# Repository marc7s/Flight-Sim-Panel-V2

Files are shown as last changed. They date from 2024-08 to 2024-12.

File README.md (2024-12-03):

# Flight Sim Panel V2
A rework of the [Flight Sim Panel V2](https://forums.flightsimulator.com/t/3d-printed-flight-simulator-panel-v2/219057) by [Aaron Cobb](https://www.cobbinnovation.com/).

I have modified some of the 3D models, and refactored the code. Here's what the finished product looks like.

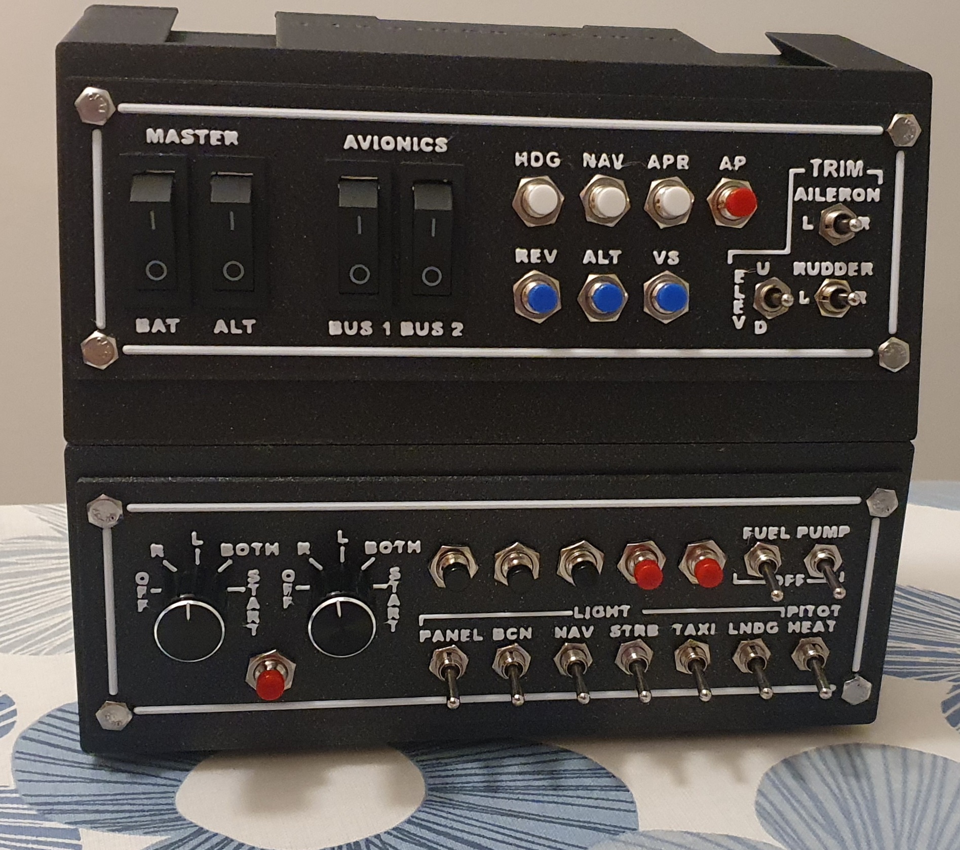
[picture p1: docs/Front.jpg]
Front


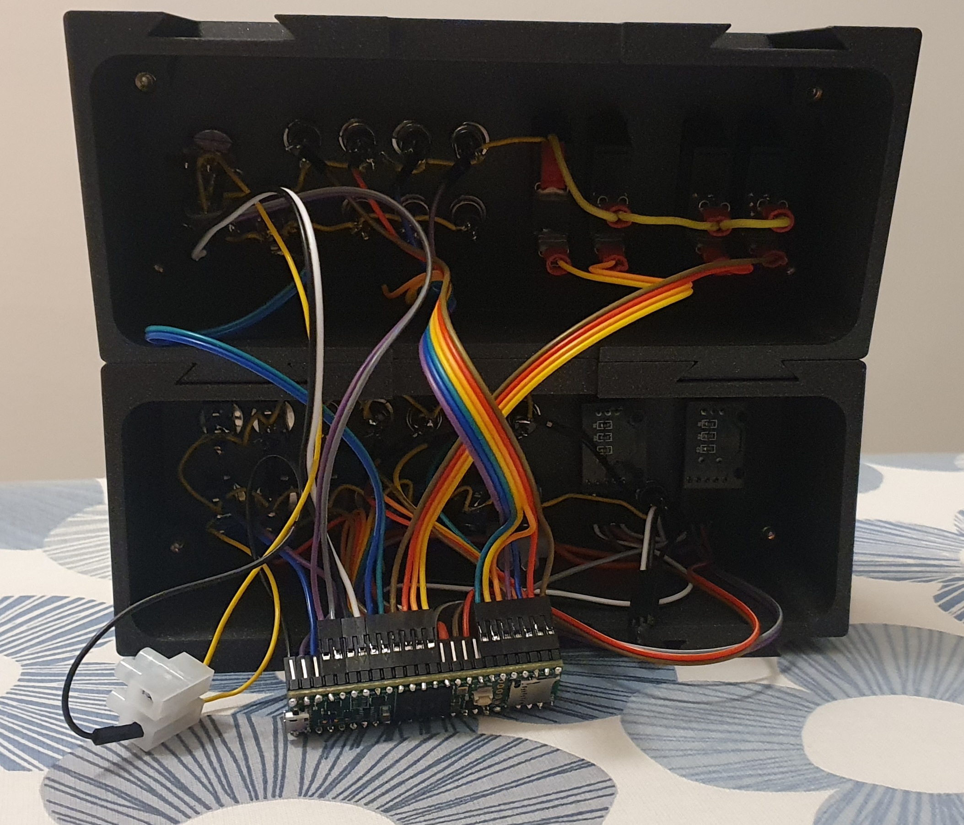
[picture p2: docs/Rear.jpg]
Rear


# Source code refactor
The main point of the refactor was to make it easier to have different pin layouts than the original, to make it more flexible. Note however, that this is of course at your own risk. It is up to you to make sure you do not reuse pins, or cause short-circuits or in any way harm the equipment.

The configuration has been migrated to variables, where the pin numbers and joystick bindings are set in a single place. To change the pin layout, or the joystick mapping for that matter, you therefore only need to change the code in a single place.

# 3D models
I only provide the 3D models that I have modified. There are a lot more available from Aaron Cobb in the previously linked forum post. I have recreated two enclosures to fit threaded inserts for mounting the panels. For each enclosure, you will need a panel. These are found among those 3D models by Aaron Cobb. The exception is the `PNL-MSTR-Auto-Trim` which I have recreated since the button holes were the incorrect size (3,05mm radius instead of 3,5mm like the rest). This version has the correct size button holes, so the buttons fit without having to drill them. This project as seen in the images was created with two stacked enclosures (0deg bottom, 15deg top) with the `PNL-MSTR-Auto-Trim` top panel and `PNL-Mags-Lights-Fuel-Xtra` bottom panel in mind. However, you are free to create any setup you want, although you might need to modify the code and/or 3D models in that case.

The modular enclosures have been modified to fit threaded inserts, to avoid any damage to the plastic parts caused by screwing directly into the printed part. Each enclosure uses 4 threaded inserts. I used the [M4x8,1 threaded inserts from CNCKitchen](https://cnckitchen.store/products/gewindeeinsatz-threaded-insert-m4-standard-50-stk-pcs). The hole for the insert is 5,6mm in diameter, in line with the specifications for that specific threaded insert, should you find other alternatives that work with the same hole diameter.

I have provided Autodesk Fusion 360 project files for all models I have created so you can easily modify them to your need, under the terms of the license. I also recreated the blank panel, should you want to more easily create your own panels in Fusion 360 without having to work with the blank STL file.

# Thoughts and recommendations
After building this project, I have a few recommendations to make. Firstly, by far the most tedious and delicate part was soldering wires to the components and the Teensy. The margins are pretty small, and making sure all solder points give good connections without any accidental solder bridges, in combination with the cable strain causing solders to break made it an annoying process. Especially since the components are not made for direct wire soldering, and all look different. At that point, I decided to switch strategy and bought a kit for JST and Dupont connectors, which I had considered from the start but decided to try soldering first. JST connectors are superior, but unfortunately my XH-xA connectors had protrusions on the sides, meaning I could not put multiple connectors next to each other. Therefore, I opted for the Dupont connectors which are completely flush. Crimping the connectors was a bit tedious, but the connections were much easier to handle and more reliable, and allowed me to group them logically with regards to the components. If I would do this again, I would definately use Dupont connectors from the start, and also put in the extra time to crimp connectors for the component side as well, although the components do have different connector types which is rather annoying.

Also, I definately recommend printing the panels with a different color for the text, as it was hard to read on the single filament panels I printed in the beginning. In the end, I printed new multi material panels and transferred all components to them. I do not have multiple extruders, or a multi material unit for my printer, but printing multi material manually is easy with just a single filament change as in this case. I have provided the GCode for my Prusa MK4 for multi material (black and white Prusament PLA) with a single extruder, that prints the two mentioned panels with a manual filament change for the text. Should you have a different printer, filaments, or a multi material unit, you can as mentioned get the panels from Aaron Cobb and slice them yourself. This is a picture of the provided panels in single extruder multi material mode:

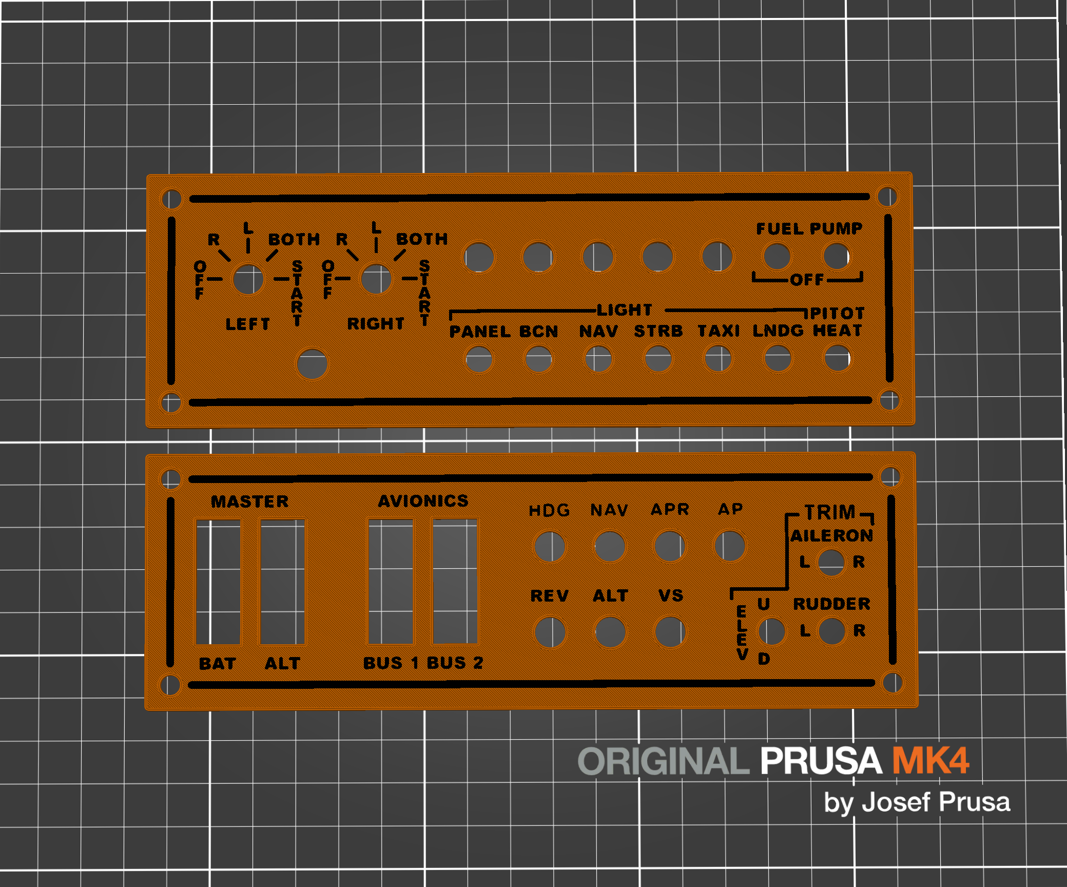
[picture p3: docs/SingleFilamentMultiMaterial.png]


Finally, I would use longer wires as short wires cause more strain and limit the positioning of the Teensy. I used longer wires for the top panel, but the shorter wires for the bottom panel were slightly too short meaning the Teensy was pretty difficult to position well. I designed a holder for the Teensy, but as it is already rather cramped inside the enclosures, and my wires were too short, I did not include it here or implement it in the design.

# Component list

Aaron Cobb also provided a component list in the linked forum post, however I am based in Europe and could therefore not find exactly the same components. Should you also face the same issue, I have also included the mounting hole sizes so you can find alternatives.

## Teensy microcontroller

* 1x [Teensy 4.1](https://www.amazon.se/dp/B08CXTSJV6)
* 2x [Male Pin Header](https://www.amazon.se/dp/B07DBY753C), more than 2 included in this kit

## Panel mounting to enclosure

Note that this is optional, but recommended. Alternatively you could use screws directly into the plastic, but this will of course damage the plastic and may cause them to come loose if you reuse the screw holes multiple times (for example when removing and putting the panel back on). Therefore, using threaded inserts is my recommendation which also provide better rigidity in the mounting.

* 4x per enclosure (8 total for this configuration) [5,6mm diameter M4 threaded inserts](https://cnckitchen.store/products/gewindeeinsatz-threaded-insert-m4-standard-50-stk-pcs)
* 4x per enclosure (8 total for this configuration) M4 machine screws

## MSTR Auto Trim panel

* 4x [Rocker Switches](https://www.amazon.se/dp/B00WJLF8OQ), mount hole size 10,2 x 29mm
* 7x [Momentary Push Buttons](https://www.amazon.se/dp/B07XRKN3F3), mount hole diameter 7mm
* 3x [Momentary Mini Toggle Switches](https://www.amazon.se/dp/B01M0LXR0L), mount hole diameter 6mm

## Mags Lights Fuel Xtra panel

* 2x [KY-040 Rotary Encoders](https://www.amazon.se/dp/B0D12N311C), mount hole size 7mm
* 6x [Momentary Push Buttons](https://www.amazon.se/dp/B07XRKN3F3), mount hole diameter 7mm
* 9x [Mini Toggle Switches](https://www.amazon.se/dp/B0B56S4F1X), mount hole diameter 6mm

# License
This work is shared under the same license as the original work, CC BY-NC-SA 4.0, in line with the license terms.

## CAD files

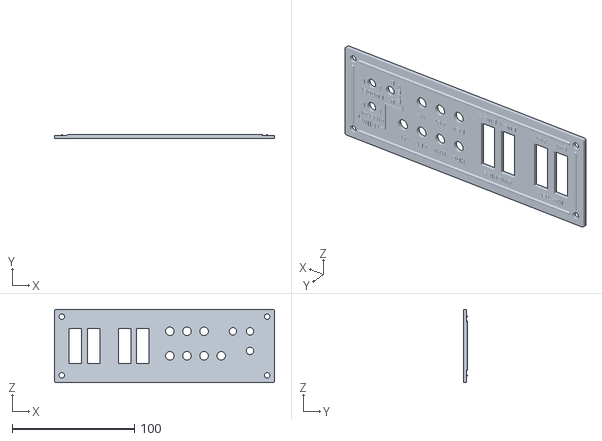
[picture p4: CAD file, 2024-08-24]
3D models/PNL-MSTR-Auto-Trim.stl
180.0 x 3.00 x 60.0

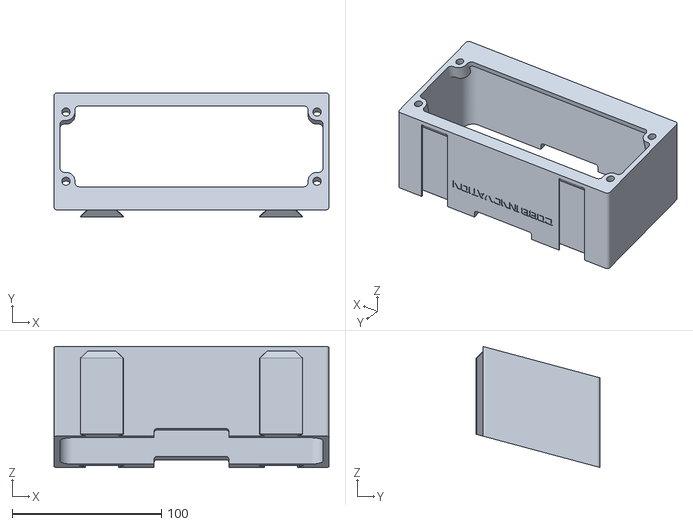
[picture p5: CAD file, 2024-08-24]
3D models/FP_ModularEnclosure_15-deg.stl
184.0 x 83.1 x 81.0

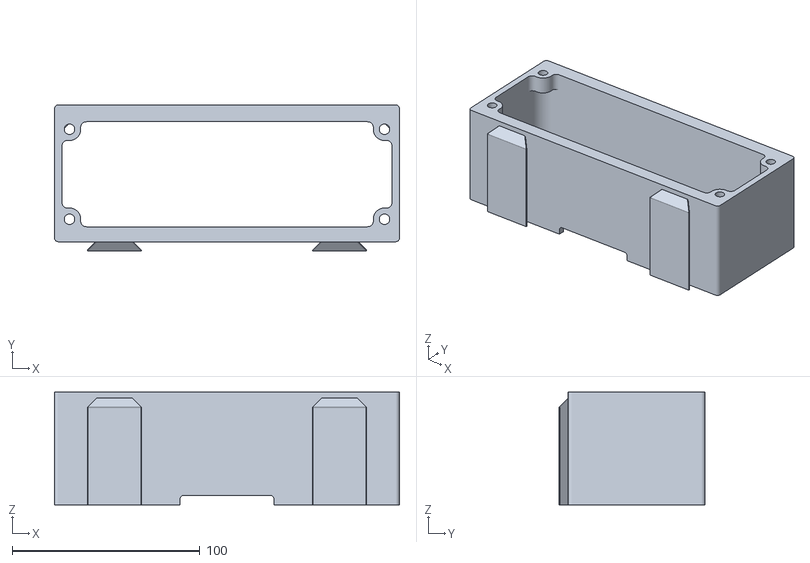
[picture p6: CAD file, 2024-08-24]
3D models/FP_ModularEnclosure_0-deg.stl
184.0 x 78.0 x 60.0

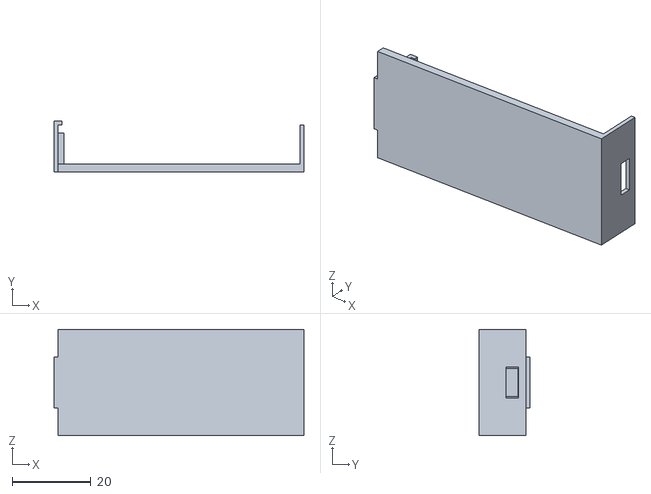
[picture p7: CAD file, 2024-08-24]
3D models/Teensy 4.1 Mount.stl
63.5 x 13.0 x 27.0

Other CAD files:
3D models/Flight Panel Blank.f3d
3D models/Modular Enclosure 0 deg.f3d
3D models/PNL-MSTR-Auto-Trim.f3d
3D models/Teensy 4.1 Mount.f3d

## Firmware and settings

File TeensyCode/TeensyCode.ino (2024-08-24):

/*
   Flight Sim Panel V2
   Created by Aaron Cobb, Refactored by Marcus Schagerberg
   https://www.cobbinnovation.com
   Board Used:		Teensy 4.1
   USB Type:		Flight Sim Controls + Joystick
   Upper Panel: PNL-MSTR-Auto-Trim
   Lower Panel: PNL-Mags-Lights-Fuel-Xtra


Following are the mapping between the components and the bindings, where you configurate the pin (on the Teensy board) and the joystick button/hat (that will be emulated by the Teensy)

***UPPER PANEL***		*Wired to right side of board, when looking at the side with the USB and SD card slot*
Rocker Switches
	Battery			      Rocker_Binding_Battery
	Alternator	      Rocker_Binding_Alternator
	Bus 1			        Rocker_Binding_Bus1
	Bus 2			        Rocker_Binding_Bus2
Momentary Buttons Group #1
	HDG				        Button_Binding_HDG
	NAV				        Button_Binding_NAV
	APR				        Button_Binding_APR
	AP				        Button_Binding_AP
	REV				        Button_Binding_REV
	ALT				        Button_Binding_ALT
	VS				        Button_Binding_VS
Trim Momentary Toggles
	Aileron Left	    Trim_Binding_AileronLeft
	Aileron Right	    Trim_Binding_AileronRight
	Rudder Left		    Trim_Binding_RudderLeft
	Rudder Right	    Trim_Binding_RudderRight
	Elevator Up		    Trim_Binding_ElevatorUp
	Elevator Down	    Trim_Binding_ElevatorDown
***LOWER PANEL***		*Wired to left side of board, when looking at the side with the USB and SD card slot*
Toggle Switches
  Fuel Pump Left	  Toggle_Binding_FuelPumpLeft
	Fuel Pump Right	  Toggle_Binding_FuelPumpRight
	Pitot Heat		    Toggle_Binding_PitotHeat
	LNDG			        Toggle_Binding_LNDG
	TAXI			        Toggle_Binding_TAXI
	STRB			        Toggle_Binding_STRB
	NAV				        Toggle_Binding_NAV
	BCN				        Toggle_Binding_BCN
	Panel			        Toggle_Binding_Panel
Momentary Buttons Group #2 *From left to right, starting with the button between the rotary encoders*
	BetweenRotaries	  Button_Binding_BetweenRotaries
	Unlabeled 1		    Button_Binding_Unlabeled1
	Unlabeled 2		    Button_Binding_Unlabeled2
	Unlabeled 3		    Button_Binding_Unlabeled3
	Unlabeled 4		    Button_Binding_Unlabeled4
	Unlabeled 5		    Button_Binding_Unlabeled5
Rotary Encoders *Note that they are run in low performance polling mode without interrupts* Also note that you need to wire them to ground and Vcc as well, and that CLK is CW and DT is CCW
  KnobLeft CCW	    Knob_Binding_LeftCCW
	KnobLeft CW		    Knob_Binding_LeftCW
	KnobLeft Click	  Knob_Binding_LeftClick
	KnobRight CCW	    Knob_Binding_RightCCW
	KnobRight CW	    Knob_Binding_RightCW
	KnobRight Click	  Knob_Binding_RightClick
*/
#include <Bounce.h>
struct ButtonBinding {
  int Pin;
  int JoystickButton;
  Bounce* Button = nullptr;
};

struct HatBinding {
  int Pin;
  int JoystickHat;
  Bounce* Button = nullptr;
};

// ***** Pin bindings *****
// Each binding has a pin number and a joystick button/hat. Configure them here below
// The bindings also contain a pointer to the joystick emulation, which is set up later
// Most also define an array of the bindings, so that they can be iterated later. Leave these arrays unless you add or remove bindings
// ***UPPER PANEL***
// Rocker Switches
ButtonBinding Rocker_Binding_Battery =          { 17, 1 };
ButtonBinding Rocker_Binding_Alternator =       { 16, 2 };
ButtonBinding Rocker_Binding_Bus1 =             { 15, 3 };
ButtonBinding Rocker_Binding_Bus2 =             { 14, 4 };
ButtonBinding* Rocker_Switches[] = { &Rocker_Binding_Battery, &Rocker_Binding_Alternator, &Rocker_Binding_Bus1, &Rocker_Binding_Bus2 };

// Momentary Buttons Group #1
ButtonBinding Button_Binding_HDG =              { 36, 5 };
ButtonBinding Button_Binding_NAV =              { 35, 6 };
ButtonBinding Button_Binding_APR =              { 34, 7 };
ButtonBinding Button_Binding_AP =               { 33, 8 };
ButtonBinding Button_Binding_REV =              { 39, 9 };
ButtonBinding Button_Binding_ALT =              { 38, 10 };
ButtonBinding Button_Binding_VS =               { 37, 11 };
ButtonBinding* MomentaryButtons1[] = { &Button_Binding_HDG, &Button_Binding_NAV, &Button_Binding_APR, &Button_Binding_AP, &Button_Binding_REV, &Button_Binding_ALT, &Button_Binding_VS };

// Trim Momentary Toggles
HatBinding Trim_Binding_AileronLeft =           { 22, 315 };
HatBinding Trim_Binding_AileronRight =          { 23, 45 };
HatBinding Trim_Binding_RudderLeft =            { 21, 270 };
HatBinding Trim_Binding_RudderRight =           { 20, 90 };
HatBinding Trim_Binding_ElevatorUp =            { 19, 0 };
HatBinding Trim_Binding_ElevatorDown =          { 18, 180 };
HatBinding* TrimToggles[] = { &Trim_Binding_AileronLeft, &Trim_Binding_AileronRight, &Trim_Binding_RudderLeft, &Trim_Binding_RudderRight, &Trim_Binding_ElevatorUp, &Trim_Binding_ElevatorDown };

// ***LOWER PANEL***
// Toggle Switches
ButtonBinding Toggle_Binding_FuelPumpLeft =     { 0, 12 };
ButtonBinding Toggle_Binding_FuelPumpRight =    { 1, 13 };
ButtonBinding Toggle_Binding_PitotHeat =        { 8, 20 };
ButtonBinding Toggle_Binding_LNDG =             { 7, 19 };
ButtonBinding Toggle_Binding_TAXI =             { 6, 18 };
ButtonBinding Toggle_Binding_STRB =             { 5, 17 };
ButtonBinding Toggle_Binding_NAV =              { 4, 16 };
ButtonBinding Toggle_Binding_BCN =              { 3, 15 };
ButtonBinding Toggle_Binding_Panel =            { 2, 14 };
ButtonBinding* ToggleSwitches[] = { &Toggle_Binding_FuelPumpLeft, &Toggle_Binding_FuelPumpRight, &Toggle_Binding_PitotHeat, &Toggle_Binding_LNDG, &Toggle_Binding_TAXI, &Toggle_Binding_STRB, &Toggle_Binding_NAV, &Toggle_Binding_BCN, &Toggle_Binding_Panel };

// Momentary Buttons Group #2
ButtonBinding Button_Binding_BetweenRotaries =  { 27, 21 };
ButtonBinding Button_Binding_Unlabeled1 =       { 28, 22 };
ButtonBinding Button_Binding_Unlabeled2 =       { 29, 23 };
ButtonBinding Button_Binding_Unlabeled3 =       { 30, 24 };
ButtonBinding Button_Binding_Unlabeled4 =       { 31, 25 };
ButtonBinding Button_Binding_Unlabeled5 =       { 32, 26 };
ButtonBinding* MomentaryButtons2[] = { &Button_Binding_BetweenRotaries, &Button_Binding_Unlabeled1, &Button_Binding_Unlabeled2, &Button_Binding_Unlabeled3, &Button_Binding_Unlabeled4, &Button_Binding_Unlabeled5 };

// Rotary Encoders
ButtonBinding Knob_Binding_LeftCCW =            { 12, 30 };
ButtonBinding Knob_Binding_LeftCW =             { 11, 31 };
ButtonBinding Knob_Binding_LeftClick =          { 25, 32 };
ButtonBinding Knob_Binding_RightCCW =           { 10, 27 };
ButtonBinding Knob_Binding_RightCW =            { 9, 28 };
ButtonBinding Knob_Binding_RightClick =         { 24, 29 };

// ***** End of pin bindings *****

// Set up Rotary Encoders turning
#include <Encoder.h>
Encoder Knob_Left (Knob_Binding_LeftCCW.Pin, Knob_Binding_LeftCW.Pin);
long positionKnobLeft = 0;
Encoder Knob_Right (Knob_Binding_RightCCW.Pin, Knob_Binding_RightCW.Pin);
long positionKnobRight = 0;

// Toggles a joystick button, turning it on and off after a short delay
void toggleButton(int buttonID) {
  Joystick.button(buttonID, 1);
  delay(50);
  Joystick.button(buttonID, 0);
}

void setup() {
  // ***** Set up joystick bindings *****
  // 10 = 10 ms debounce time
  // Rocker Switches
  for (auto binding : Rocker_Switches)
    binding->Button = new Bounce(binding->Pin, 10);

  // Momentary Buttons Group #1
  for (auto binding : MomentaryButtons1)
    binding->Button = new Bounce(binding->Pin, 10);
  
  // Trim Momentary Toggles
  for (auto binding : TrimToggles)
    binding->Button = new Bounce(binding->Pin, 10);

  // Toggle Switches
  for (auto binding : ToggleSwitches)
    binding->Button = new Bounce(binding->Pin, 10);

  // Momentary Buttons Group #2
  for (auto binding : MomentaryButtons2)
    binding->Button = new Bounce(binding->Pin, 10);

  //Rotary Push buttons
  Knob_Binding_LeftClick.Button = new Bounce(Knob_Binding_LeftClick.Pin, 10);
  Knob_Binding_RightClick.Button = new Bounce(Knob_Binding_RightClick.Pin, 10);

  // ***** End of joystick bindings setup *****
  
  // Same as Windows default
  Joystick.Z(512);
  Joystick.X(512);
  Joystick.Y(512);
  Joystick.Zrotate(512);
  Joystick.sliderLeft(512);
  Joystick.sliderRight(512);
  Joystick.hat(-1);
  
  // ***** Set up pullup resistors on pins *****
  // Rocker Switches Pullup
  for (auto binding : Rocker_Switches)
    pinMode(binding->Pin, INPUT_PULLUP);

  // Momentary Buttons Group #1 Pullup
  for (auto binding : MomentaryButtons1)
    pinMode(binding->Pin, INPUT_PULLUP);

  // Trim Momentary Toggles Pullup
  for (auto binding : TrimToggles)
    pinMode(binding->Pin, INPUT_PULLUP);

  // Toggle Switches Pullup
  for (auto binding : ToggleSwitches)
    pinMode(binding->Pin, INPUT_PULLUP);

  // Momentary Buttons Group #2 Pullup
  for (auto binding : MomentaryButtons2)
    pinMode(binding->Pin, INPUT_PULLUP);

  // Rotary Encoders Pullup
  pinMode(Knob_Binding_LeftClick.Pin, INPUT_PULLUP);
  pinMode(Knob_Binding_RightClick.Pin, INPUT_PULLUP);

  // ***** End of pullup resistors setup *****
}

void loop() {
  // Update all the buttons.  There should not be any long delays in loop(), so this runs repetitively at a rate faster than the buttons could be pressed and released
  // ***** Joystick update *****
  // Update Rocker Switches
  for (auto binding : Rocker_Switches)
    binding->Button->update();

  // Update Momentary Buttons Group #1
  for (auto binding : MomentaryButtons1)
    binding->Button->update();

  // Update Trim Momentary Toggles
  for (auto binding : TrimToggles)
    binding->Button->update();

  // Update Toggle Switches
  for (auto binding : ToggleSwitches)
    binding->Button->update();

  // Update Momentary Buttons Group #2
  for (auto binding : MomentaryButtons2)
    binding->Button->update();

  // Update Rotary Encoders
  Knob_Binding_RightClick.Button->update();
  Knob_Binding_LeftClick.Button->update();

  // ***** End of joystick update *****
    
  // ***** Joystick status changes *****
  // Rocker Switches Update if Falling
  for (auto binding : Rocker_Switches) {
    if (binding->Button->fallingEdge() || binding->Button->risingEdge())
      toggleButton(binding->JoystickButton);
  }

  // Momentary Buttons Group #1 Update if Falling
  for (auto binding : MomentaryButtons1) {
    if (binding->Button->fallingEdge())
      Joystick.button(binding->JoystickButton, 1);
    
    if (binding->Button->risingEdge())
      Joystick.button(binding->JoystickButton, 0);
  }

  // Trim Momentary Toggles Update if Falling
  for (auto binding : TrimToggles) {
    if (binding->Button->fallingEdge())
      Joystick.hat(binding->JoystickHat);

    if (binding->Button->risingEdge())
      Joystick.hat(-1);
  }

  // Toggle Switches Update if Falling or Rising
  for (auto binding : ToggleSwitches) {
    if (binding->Button->fallingEdge() || binding->Button->risingEdge())
      toggleButton(binding->JoystickButton);
  }

  // Momentary Buttons Group #2 Update if Falling or Rising
  for (auto binding : MomentaryButtons2) {
    if (binding->Button->fallingEdge())
      Joystick.button(binding->JoystickButton, 1);
    
    if (binding->Button->risingEdge())
      Joystick.button(binding->JoystickButton, 0);
  }

  // Rotary Push Buttons Update if Falling or Rising
  if (Knob_Binding_RightClick.Button->fallingEdge())
	  Joystick.button(Knob_Binding_RightClick.JoystickButton, 1);
  if (Knob_Binding_RightClick.Button->risingEdge())
	  Joystick.button(Knob_Binding_RightClick.JoystickButton, 0);
  
  if (Knob_Binding_LeftClick.Button->fallingEdge())
	  Joystick.button(Knob_Binding_LeftClick.JoystickButton, 1);
  if (Knob_Binding_LeftClick.Button->risingEdge())
	  Joystick.button(Knob_Binding_LeftClick.JoystickButton, 0);

  // Rotary Encoders Update if Falling or Rising
  long newKnobRight;
  newKnobRight = Knob_Right.read();
  if (newKnobRight > (positionKnobRight + 3)) {
    toggleButton(Knob_Binding_RightCW.JoystickButton);
    Knob_Right.write(0);
  }
  if (newKnobRight < (positionKnobRight - 3)) {
    toggleButton(Knob_Binding_RightCCW.JoystickButton);
    Knob_Right.write(0);
  }
  
  long newKnobLeft;
  newKnobLeft = Knob_Left.read();
  if (newKnobLeft > (positionKnobLeft + 3)) {
    toggleButton(Knob_Binding_LeftCW.JoystickButton);
    Knob_Left.write(0);
  }
  if (newKnobLeft < (positionKnobLeft - 3)) {
    toggleButton(Knob_Binding_LeftCCW.JoystickButton);
    Knob_Left.write(0);
  }

  // ***** End of joystick status changes *****
}
